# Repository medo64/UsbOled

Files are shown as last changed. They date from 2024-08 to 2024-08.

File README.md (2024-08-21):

## USB OLED ##

USB OLED allows a USB CDC serial connection to SSD1306 OLED Display Modules.

### Protocol ###

This driver will present itself to the system as CDC USB device. Communication
protocol is text-based and available [here](https://github.com/medo64/UsbOled.Firmware).

---

*You can check my blog and other projects at [www.medo64.com](https://www.medo64.com/electronics/).*

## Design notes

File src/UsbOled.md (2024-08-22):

## Hardware

### Properties

| | |
|---|---:|
| Dimensions | 27.4 x 12.0 mm |
| Voltage | 5 V ±10% |
| Current | 100 mA |

### Parts

|  # | Part | RefDes  | DigiKey Part Number |
|---:|---|---|---|
|  1 | C 100nF X7R 16V (0805) | C1 | 478-5311-1-ND |
|  2 | C 1uF 16V X7R (0805) | C2-C3 | 1276-6471-1-ND |
|  1 | DS LED (0805) | DS1 | 475-1415-1-ND |
|  1 | J USB 2.0 (C) | J1 | USB4085-GF-A |
|  1 | J Header Female (4w) | J2 | S7002-ND |
|  1 | L Ferrite 1A 40Ohm (0805) | L1 | 445-2201-1-ND |
|  3 | R 5.1K 0.125W (0805) | R1-R3 | RMCF0805FT5K10CT-ND |
|  1 | U PIC16F1454-I/ST (SSOP-14) | U1 | PIC16F1454-I/ST-ND  |

#### Optional I²C Pull-Up

OLED display is expected to have a pull-up resistors for I²C line (commonly
`4.7K`). No additional I²C resistors are usually required.

If additional I²C pull-ups are needed there are 2 resistor footprints available
on the OLED side that can be populated. E.g., adding `5.1K` pull-ups if `4.7K`
pull up is already available will result in `2.45K` pull-up value. Such strong
pull up is not really necessary but it also shouldn't hurt.

Pull-ups are taken from internal PIC 3.3V line.

---

*You can check my blog and other projects at [www.medo64.com](https://www.medo64.com/electronics/)*

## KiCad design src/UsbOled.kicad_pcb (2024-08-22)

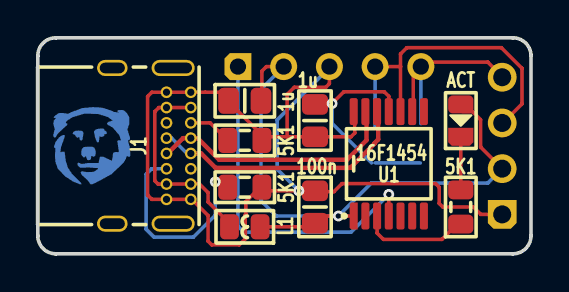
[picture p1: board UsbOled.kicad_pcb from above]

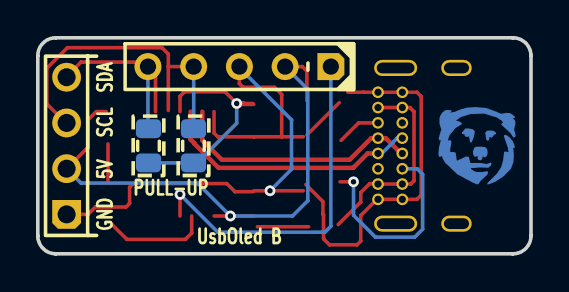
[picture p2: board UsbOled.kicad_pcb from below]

Board: 2 copper layers, 27.4 x 12.0 mm, 15 parts (5 on the bottom side), 13 nets.

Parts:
C1: 100n; C (0805)
C2, C3: 1u; C (0805)
DS1: ACT; DS (0805)
DS2: I2C OLED 128x32; DS OLED 128x32 I2C (4w)
ICON: Medo64; ICON Medo64
ICSP: Microchip PIC; ICSP PIC Pogo (5w)
J1: ‎USB4085; J USB C 2.0 Receptacle (16w)
L1: 40R; L Ferrite (0805)
R1, R2, R3: 5K1; R (0805)
R4, R5: 5K1; R Optional (0805)
U1: 16F1454; U Micro [PIC16F1454] (TSSOP-14)

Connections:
3V3: C3.2, R4.2, R5.2, U1.11
5V: C1.2, C2.2, DS1.2, DS2.2, ICSP.2, L1.1, U1.1
GND: C1.1, C2.1, C3.1, DS2.1, ICSP.3, J1.A01, J1.A12, J1.B01, J1.B12, R1.1, R2.1, U1.14
ICSP_VPP: ICSP.1, U1.4
LED_ACTIVE: DS1.1, R3.2
OLED_SCL: DS2.3, ICSP.4, R4.1, U1.10
OLED_SDA: DS2.4, ICSP.5, R5.1, U1.9
OUT_LED_ACTIVE: R3.1, U1.3
USB_CC1: J1.A05, R1.2
USB_CC2: J1.B05, R2.2
USB_DM: J1.A07, J1.B07, U1.12
USB_DP: J1.A06, J1.B06, U1.13
Vusb: J1.A04, J1.A09, J1.B04, J1.B11, L1.2

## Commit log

2020-12-13 Refactoring board layout
2020-12-13 Increased bulk capacitance
2020-12-14 Added extra I2C pull up resistors
2020-12-16 Refactored I2C code to work more reliably
2020-12-16 Pull up resistors go to 3V3
2020-12-16 Added config data for I2C
2020-12-17 Switching to hybrid stack
2020-12-21 Added function to clear line from current position
2020-12-21 Added option to reset the device
2020-12-23 Reducing program memory footprint slightly
2020-12-23 Fixing case fall-through for commands
2021-01-03 Added notes about capacitors and resistors
2021-01-04 Disable whole interrupt handler if not doing USB interrupt
2021-01-10 Drastically reduced LED persistence
2021-01-11 Converted static to trace vias
2023-09-12 New revision
    [UsbOled.kicad_pcb]
2023-09-13 Added optional I2C pull-up resistors
    [UsbOled.kicad_pcb]
2023-09-14 Refactored I2C pullups to use 3V3 line
    [UsbOled.kicad_pcb]
2023-09-15 Refactoring to minimum line count
    [UsbOled.kicad_pcb]
2023-09-16 Changing LED setup
    [UsbOled.kicad_pcb]
2023-09-16 Setting LED I/O as open-drain
2023-09-17 Updating tracks a bit
    [UsbOled.kicad_pcb]
2023-09-17 Updating tracks
    [UsbOled.kicad_pcb]
2024-08-21 Separated firmware into a separate repo
    [UsbOled.kicad_pcb]
2024-08-22 Minor refactorings
    [UsbOled.kicad_pcb]
